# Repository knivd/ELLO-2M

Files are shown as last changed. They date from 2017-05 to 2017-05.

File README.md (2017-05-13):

# ELLO 2M
Electronics of the ELLO 2M DIY portable computer

http://ello.cc

https://www.crowdsupply.com/yellow-beak-computer/ello-2m

https://hackaday.io/project/9692-ello-2m

http://ello.referata.com/

ELLO 2M is a a PIC32-powered portable computer for hobby and education. It is built entirely from PCBs (no other casing!).

**ELLO 2M specifications**
* 32-bit PIC32 micro-controller with 128kB RAM (512kB RAM in the ELLO 2M² “hacker” version)
* 7-inch LCD touch-screen panel with 800x480 pixel resolution
* 3x micro-SD cards – one permanently built-in and two for removable storage
* Real-time clock
* 2.4GHz RF communication module with simple communication protocol
* Small speaker
* Optional on-board serial non-volatile data RAM
* Expansion receptacle
* Electronic prototyping space with up to 1156 holes
* 4500mAh battery for up to 12 hours of continuous operation (more in power-saving mode)
* Replaceable keyboard panels
* Composite construction from PCB panels only

**ELLO Features**
* ELLO is Thin - 6.4mm total without sockets, consisting of 6 stacked PCBs.
* Prototyping space - available on ELLO Geek and above, so you can create and test your projects using ELLO. 
* Real-time clock and buzzer
* Ample storage - 3 Micro-SD card slots and an internal serial FRAM for data and code storage.
* Built in RF module - which essentially emulates a wireless UART connection and also has an internal stack with ability for simple networking with similar devices. The range (by specs) is about 100 metres.
* keyboard - 2 layered keyboard to create pushable buttons, complete with optional backlighting and indicator LED.

**With ELLO you can**
* Learn how to program in BASIC and C; more programming languages will follow soon
* Have an open field to create programs for everything; ELLO is new and your programs will be needed
* Prototype electronic circuits and control them directly from your programs
* Develop own expansion boards
* Write your own games
* Play alone or connected with friends

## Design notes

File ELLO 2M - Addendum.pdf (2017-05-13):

# MMBasic for ELLO 2M and ELLO 2M² computers

# Addendum

to
Micromite MMBasic (original document) (http://geoffg.net/Downloads/Micromite/Micromite%20Manual.pdf)

# Micromite PLUS Addendum (original document) (http://geoffg.net/Downloads/Micromite/Micromite%20Plus%20Addendum.pdf)

MMBasic is a powerful implementation of the BASIC language with full floating point support, string variables, long variable names, multi-dimensional arrays, graphics, low-level driver support, and many more features.

The ELLO 2M and ELLO 2M²
computers use MMBasic for Micromite Plus, and also contain some additions and improvements, some of which in the form of extra commands and functions, but the majority of them invisible to the end user. These additions allow more effective utilisation of the hardware capabilities of ELLO 2M and ELLO 2M²

This manual describes only the additions and changes introduced for the support of the ELLO 2M and ELLO 2M²
computers. It does not replace the original MMBasic manual but only completes it with the additional information.

ELLO 2M and ELLO 2M²
computers are designed and manufactured by Yellow Beak Computer, Ltd. © 2015-2017
This manual is licensed under CC BY-NC-SA 3.0

© Mai 2017
Document Revision 4

ELLO 2M Keyboard

ELLO 2M and ELLO 2M²
are built as standalone computing systems with own keyboard and display. The keyboard layout is a mix of the standard US and UK keyboards with some new touch for more universality.

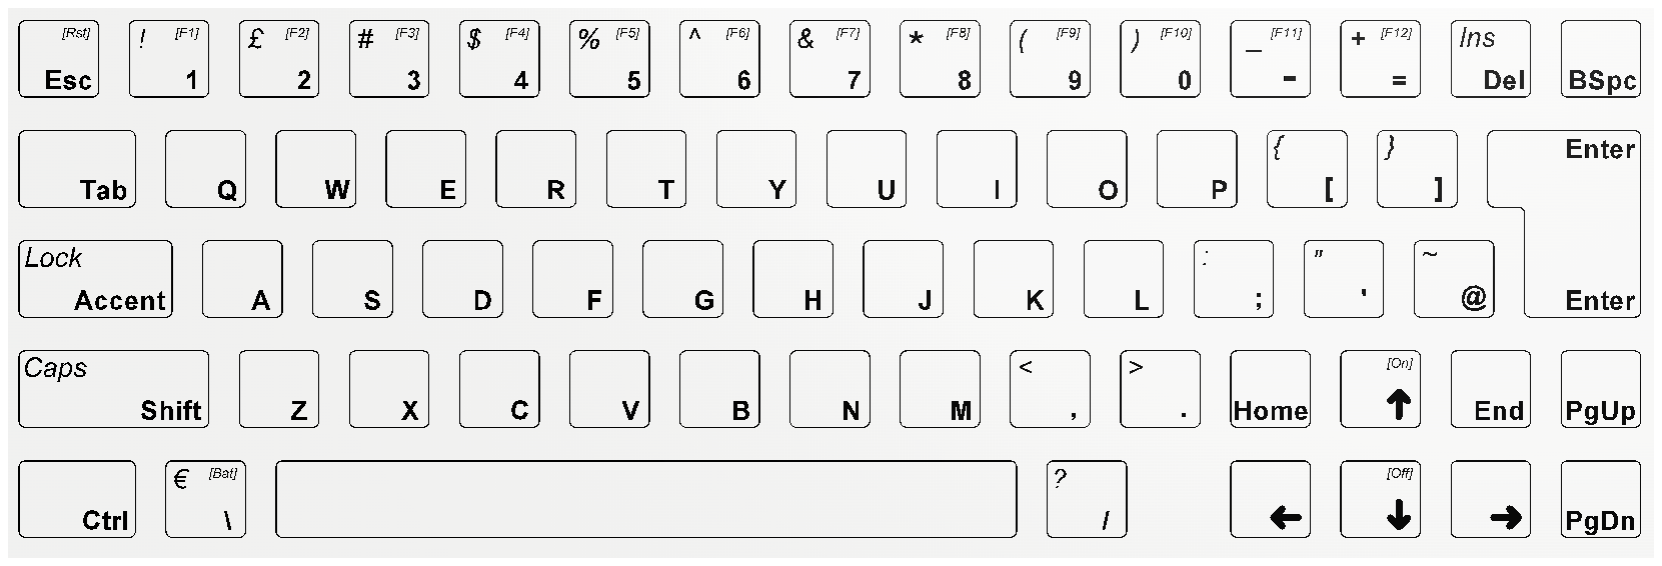
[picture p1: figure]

Some keys have small texts enclosed in square brackets, such as [F1], [Rst], etc.
These functions are accessible by pressing and holding the key “Ctrl” while pressing the key with the indicated function.

Four of the keys with text in square brackets require additional explaining:
- The key [On] is to switch the system on by holding “Ctrl” and [On] for about two seconds.
- The key [Off] switches the system off. It requires holding for about 4 seconds.
- The key [Rst] performs system reset after about 3 seconds.
- The key [Bat] is reserved for battery testing functionality in future.

An obvious difference is the “Accent” key which has replaced the traditional “Caps Lock”. It works exactly like the “Shift” key, and its function is to enable easy access to all characters from the extended part of the ASCII table. When pressed and held, and another key is pressed, it will produce a character from the extended codes of the table. The most used ones are the language accent characters such as “ë” or “ç”, hence the name of the key.

Keyboard layout in accent mode

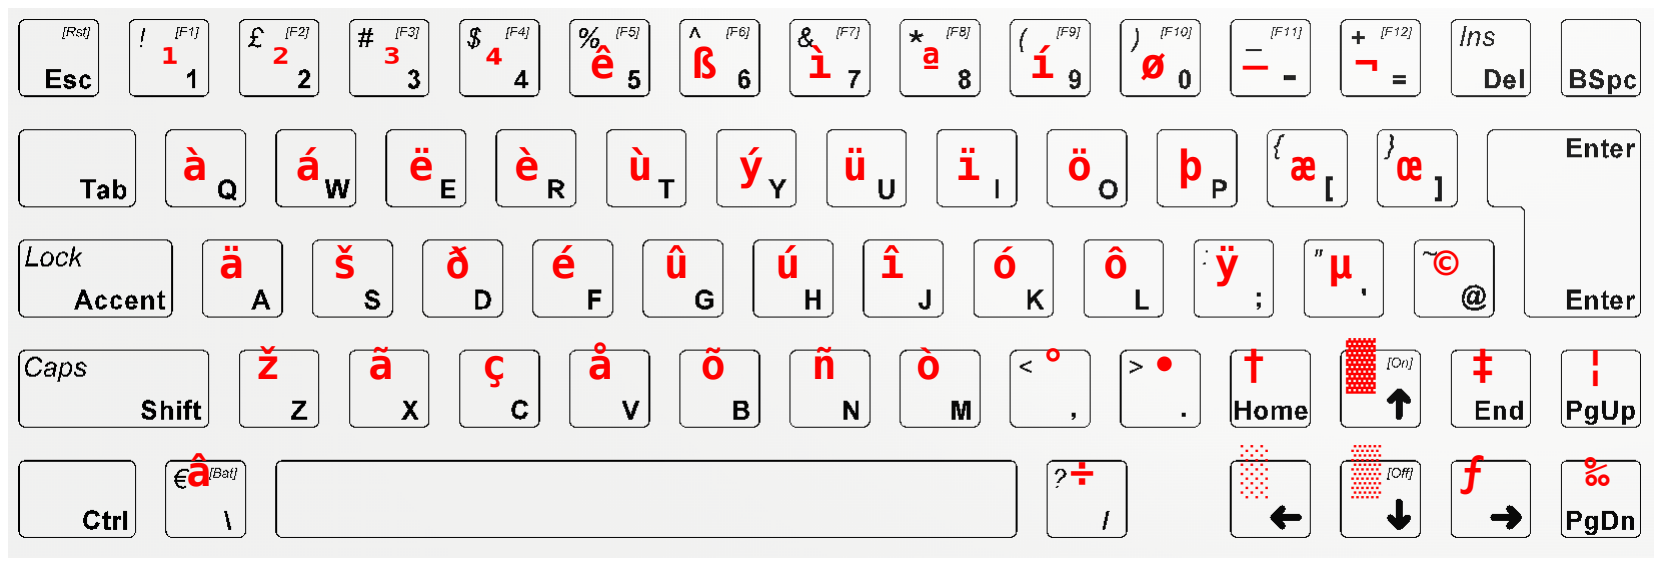
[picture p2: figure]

MMBasic Addendum for ELLO 2M and ELLO 2M²
computers | Page 2 / 10

Keyboard layout in Shift-Accent mode

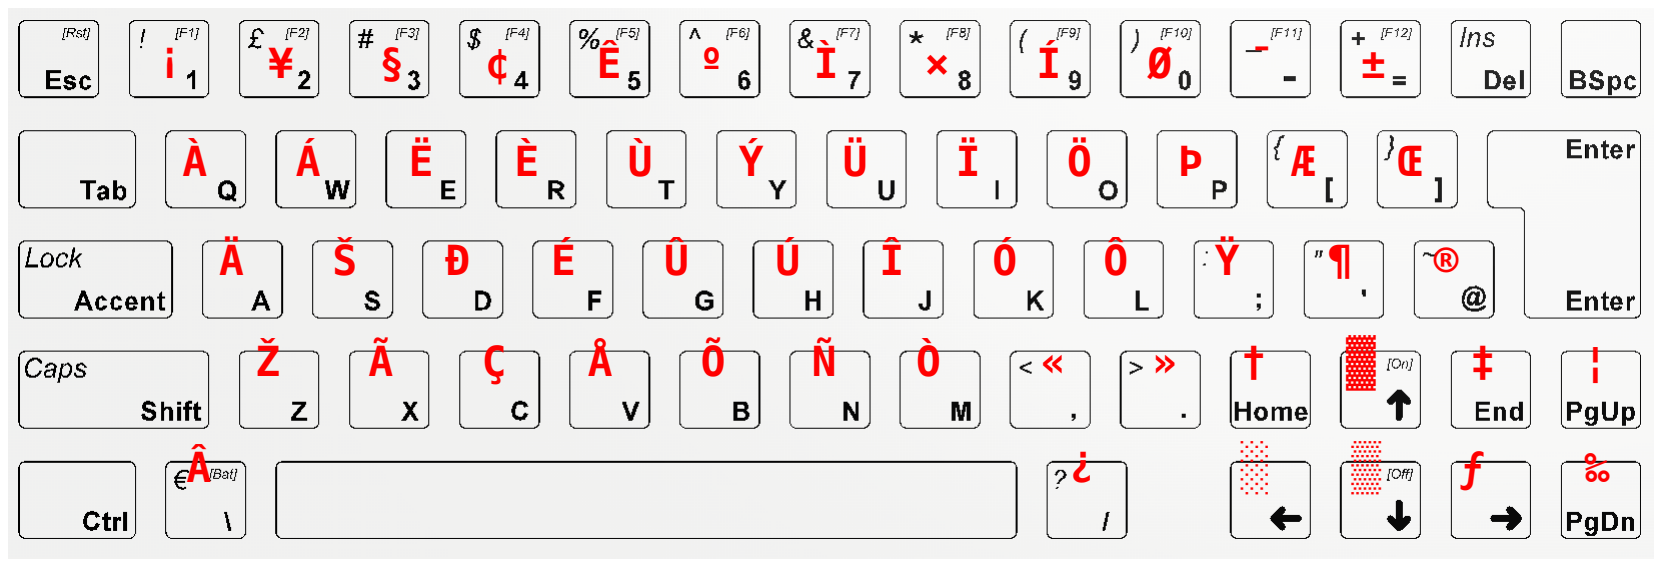
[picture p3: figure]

When the “Accent” key is double-pressed (quickly pressed twice), it enters in “Accent Lock” mode where the keyboard produces accented characters without the need to hold “Accent” continuously. Another double press cancels the mode.

The Shift character operates in the same manner – a double press of the “Shift” key is equivalent of “Caps Lock” activated.

Both “Accent” and “Shift” keys are independent and can be independently locked and unlocked – for example to continuously produce capital accented characters.

The current mode is displayed by changing the colour of the light indicator “ST”
- Normal operation mode (no lock to “Accent” or “Shift”): blue
- “Caps Lock” mode: white
- “Accent Lock” mode: yellow
- “Accent Caps Lock” mode: red

Another difference is the lack of “Insert” key. It is now moved to the “Del” key in shift mode.

Program and Data Storage

Up to five MMBasic “drives” are available for storing and loading programs and data:

- Drive “A:” (only available in ELLO 2M²
) a virtual drive using part of the internal flash memory and has size of about 800k. It can be used as general data and program storage as well as it is the default place where the help information is stored as a separate system file.
- Drives “B:”, “C:”, “D:”, and “E:” are supported in the system. With the exception of the last one, the first three hard SD card connectors installed on the PCB1 board. Supported are MMC, SD or SDHC memory cards formatted as FAT16 or FAT32 with capacities up to 64 Gigabytes.

File names must be in 8.3 format (8 characters for file name and 3 characters for extension), prefixed with an optional drive prefix A: or B: (the same as DOS or Windows).

Long file names and directories are not supported. The default drive after power on and reset events is B: and it can be changed with the command DRIVE.

During start up drive B: will be selected as default. A new drive can be selected by using the DRIVE command. For example DRIVE “C” will select drive C: as default. Once a drive has been selected, all file commands and functions will refer to files and data on that drive, until a new drive is selected by another DRIVE command.

Drive A: does not support hierarchic organisation with folders. All files in A: only exist in the root folder. However a file in A: can be made “hidden” if its name starts with the “.” character. For example the file MYPROG.BAS in A: is a normally visible file, while the file .MYPROG.BAS will not be seen in the FILES command. Making files in A: hidden can be used to protect important system files from being inadvertently deleted or corrupted in other way by the user.

When connected to a PC via USB, the A: drive appears as accessible data storage drive on the computer. This feature is always available and does not require any user interaction. In some cases that might be undesired and can be permanently disabled with command OPTION MSD OFF. If needed it can be enabled again with the command OPTION MSD ON.

Full 8-bit ASCII support

The ELLO 2M and ELLO 2M²
version of MMBasic supports the full 8-bit character table according to ISO-8859-15. Additional characters have been assigned to the unused codes as well. The full table is shown below.
A full 224-character 10x20 pixel font is also built-in as font #97. It is the default console font.

Character table in ELLO 2M and ELLO 2M²

hex | 00 | 01 | 02 | 03 | 04 | 05 | 06 | 07 | 08 | 09 | 0A | 0B | 0C | 0D | 0E | 0F
00 | NON-PRINTABLE CODES
10
20 | | ! | “ | # | $ | % | & | ‘ | ( | ) | * | + | , | - | . | /
30 | 0 | 1 | 2 | 3 | 4 | 5 | 6 | 7 | 8 | 9 | : | ; | < | = | > | ?
40 | @ | A | B | C | D | E | F | G | H | I | J | K | L | M | N | O
50 | P | Q | R | S | T | U | V | W | X | Y | Z | [ | \ | ] | ^ | _
60 | ` | a | b | c | d | e | f | g | h | i | j | k | l | m | n | o
70 | p | q | r | s | t | u | v | w | x | y | z | { | | | } | ~
80 | ░ | ▒ | ▓ | ƒ | √ | … | † | ‡ | ¦ | ‰ | ≤ | ← | ↑ | ≈ | π | Ω
90 | ∞ | ─ | ⁴ | ∫ | ¤ | │ | ½ | ¼ | ¾ | ™ | ≥ | → | ↓ | ∆ | ∏ | ∑
A0 | | ¡ | ¢ | £ | € | ¥ | Š | § | š | © | ª | « | ¬ | ― | ® | ¯
B0 | ° | ± | ² | ³ | Ž | µ | ¶ | • | ž | ¹ | º | » | Œ | œ | Ÿ | ¿
C0 | À | Á | Â | Ã | Ä | Å | Æ | Ç | È | É | Ê | Ë | Ì | Í | Î | Ï
D0 | Ð | Ñ | Ò | Ó | Ô | Õ | Ö | × | Ø | Ù | Ú | Û | Ü | Ý | Þ | ß

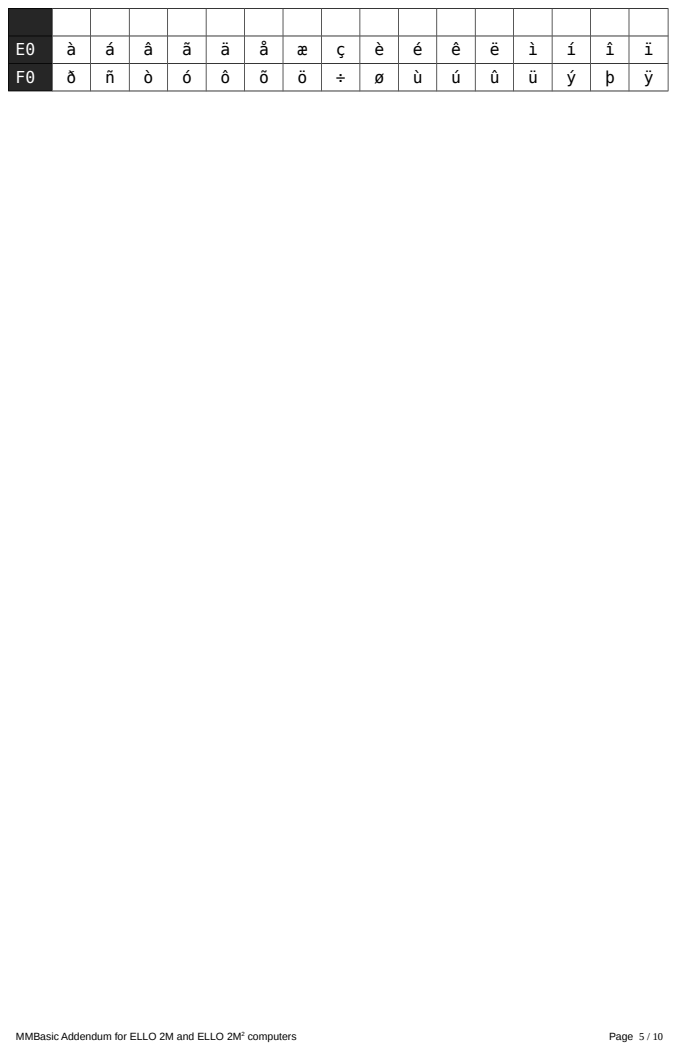
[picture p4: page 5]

IMPORTANT: A string that starts with an extended character (i.e. with ASCII code greater than 127), must be preceded by two double quotes.

Example: ""µmite"

This rule is required only if the first character of the string is an extended code.

Expansion Connector

ELLO 2M and ELLO 2M²
computers have expansion connector with pinout as shown in the pictures below. The connector is a standard 36-pin female square pin receptacle with 2.54mm (0.1”) pitch. It can be used to connect various expansion boards or prototype jumper wires.

ELLO 2M expansion connector

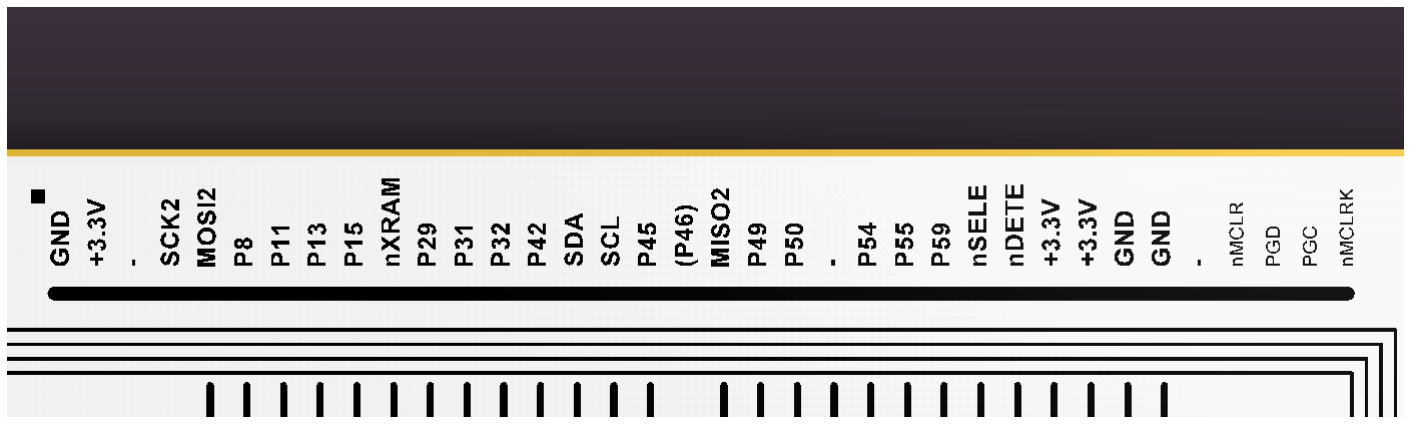
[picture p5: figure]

ELLO 2M²
expansion connector

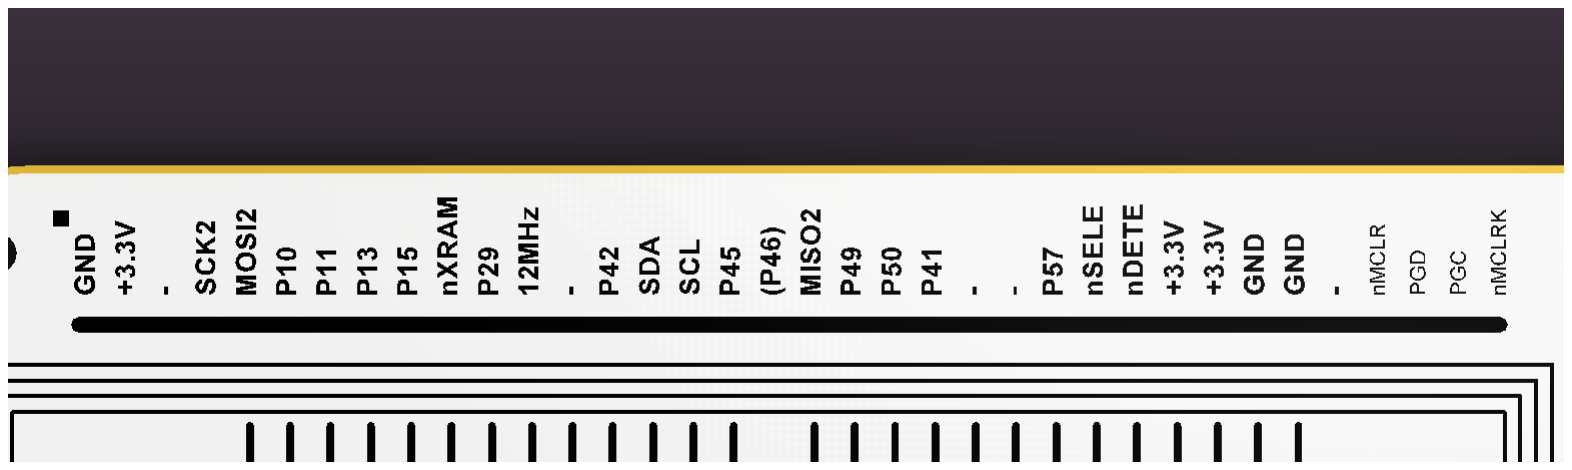
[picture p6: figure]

Prototyping space

ELLO 2M and ELLO 2M²
computers have prototyping space that can be used for building custom schematics. It offers 1156 holes. There are 4 surrounding “orbital” lanes and 3 dedicated areas. The wiring is as shown on the next page.

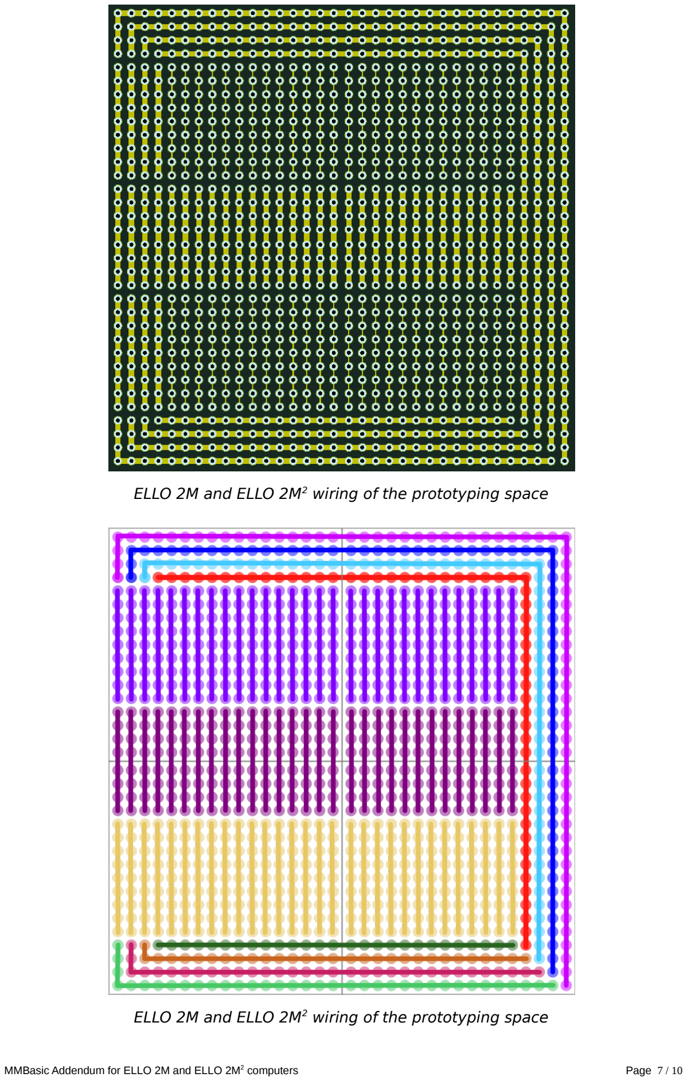
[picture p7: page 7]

ELLO 2M and ELLO 2M²
wiring of the prototyping space

ELLO 2M and ELLO 2M²
wiring of the prototyping space

Firmware Updates

MMBasic on ELLO 2M and ELLO 2M²
can update itself with a newer version of the firmware to include new features or fix previously known problems.

The command to activate this functionality is FWUPDATE. It must be executed in direct mode with the system attached to a PCB via USB cable.

Select the button “Open HEX File”. A file selection dialog will appear. Choose the file with the new firmware.

Press “Program/Verify” and wait until the process is complete.

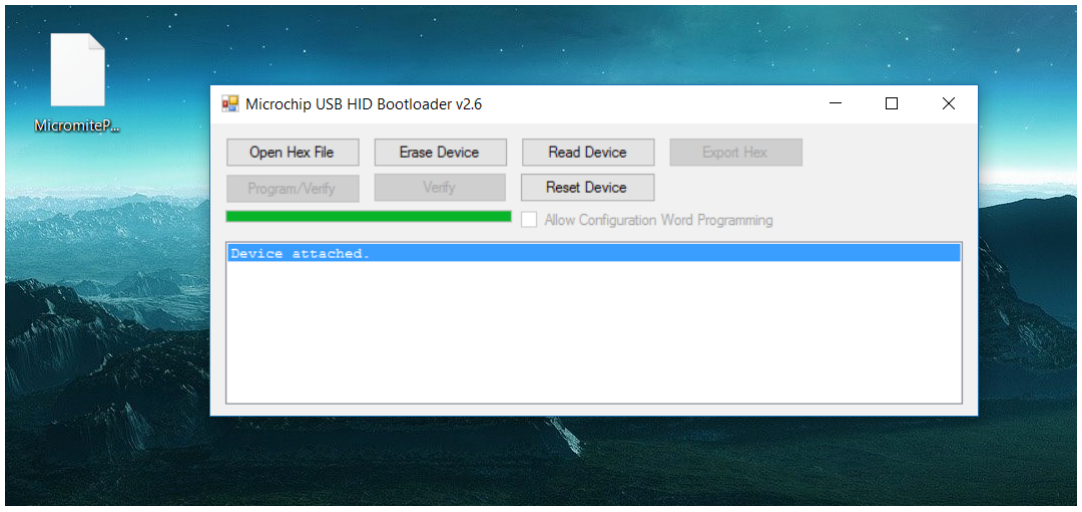
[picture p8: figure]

If due to some unfortunate event the update gets interrupted before completion (USB cable pulled out, for example), MMBasic will not be available anymore. There is a more “hardware-type” way to restore the firmware even from that situation.
Switch the system off, connect a jumper wire between the pins marked as “PGD” and “GND” on the expansion connector, and switch the system again. It will be forced back in bootloader mode.

Now remove the jumper cable (IMPORTANT!) and start the process for updating the software.

And finally, of course there is always the third option to upload new firmware by using ICD3 or Pickit3 or similar programmer. Connect the programmer using prototype jumper wires to the pins marked “MCLR” (not “MCLRK”!), “PGC”, “PGD”, “+3.3V”, and “GND”. Switch the system on and upload the new firmware using the relevant PC software such as MPLAB IPE or other.

Full list of the added or changed commands in ELLO 2M and ELLO 2M²

Note: Square brackets indicate that the parameter or characters are optional.

Sinc
e

Name and
parameters

Description

V5.2 FWUPDATE | Executes the bootloader for firmware update. The system
must be connected to a PC via USB and the firmware update software must be running.
V5.2 DRIVE drivespec$ Change the default drive used for file operations that do not specify a drive to that specified in 'drivespec$'. This can be the string “A”, “B”, “C”, “D”, or “E”
ELLO 2M allows execution of an implied DRIVE command. Hence for example DRIVE “A” can be written just as A:
See also the predefined read-only variable MM.DRIVE.
V5.3 INIT drivespec$ | Initialise (format) specified drive letter. All data on the
drive will be destroyed
V5.3 FILES [fspec$] [A]
or
DIR [fspecs$] [A]

Lists files in the current directory on the SD or internal drive (drive A:).
The SD card may use an optional ‘fspec $’. Question marks (?) will match any character and an asterisk (*) will match any number of characters. If omitted, all files will be listed. For example:
*.* | Find all entries
*.TXT | Find all entries with an extension of TXT
E*.* | Find all entries starting with E
X?X.* | Find all three letter file names starting and
ending with X
An optional parameter ‘-A’ displays the file attributes when executed on drive B: and ALL files (including the hidden ones) on drive A:
V5.3 IMAGEA CREATE
“file”
or
IMAGEA LOAD “file”

Only available in ELLO 2M²
Creates or loads full binary image of drive A:
The images are searched and created in the current active drive. When loading a new image the entire previous content of A: is destroyed

V5.3 HELP [keyword$] | Only available in ELLO 2M² Displays help information about the provided keyword. From the command line keyword$ without enclosing quotes will work for almost all system words, however it is recommended that keyword$ is always enclosed by quotes or at least the opening one is present. Examples: HELP HELP CIRCLE HELP ‘CIRCLE or HELP ‘CIRCLE’ HELP “CIRCLE or HELP “CIRCLE” The command is also able to find in many cases the most suitable match for a partial or mistyped keyword. As in the examples above HELP CICLE will lead to displaying help information about the CIRCLE command as a closest match to the parameter ‘CICLE’.
V5.3 OPTION MSD ON | OFF | Only available in ELLO 2M² Enable (parameter ON) or disable (parameter OFF) file access to the internal drive A: by a host PC via USB connection By default this function is activated. Note that the access to B: may not work on MacOS powered machines. OPTION MSD OFF is recommended in those cases.

Full list of the added or changed functions and read-only variables in ELLO 2M and ELLO 2M²

Note: Square brackets indicate that the parameter or characters are optional.

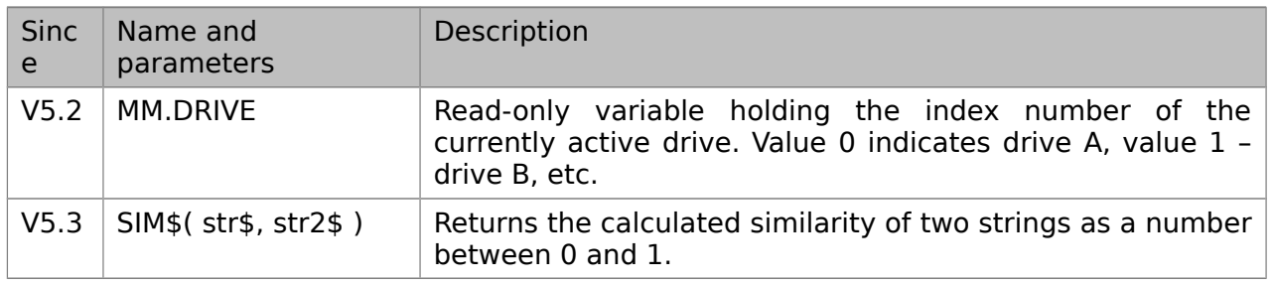
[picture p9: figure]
Sinc e; Name and parameters; Description; drive B, etc.; between 0 and 1.

V5.2 MM.DRIVE | Read-only variable holding the index number of the currently active drive. Value 0 indicates drive A, value 1 –
V5.3 SIM$( str$, str2$ ) | Returns the calculated similarity of two strings as a number

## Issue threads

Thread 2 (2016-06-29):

all pdfs are just 100kb files that are completely white

buzztiaan, 2016-06-29:
eh, oops?

knivd, 2016-06-29:
I just checked all PDFs, and they are fine. Using Adobe Reader and it opens both the schematics and the 3D renders as well.

buzztiaan, 2016-07-01:
adobe reader isnt free software

knivd, 2016-07-05:
I believe it is. The schematic files can be open with any PDF reader. I am not sure about the 3D renders though, but they are not critical

buzztiaan, 2016-07-11:
free software is not defined like you think it is

blu, 2016-07-11:
Konstantin, some of the PDFs have issues opening in evince (a very popular X11-based reader) as well as in the default PDF reader in iOS. The problematic PDFs are:

panel_MX470.pdf
PCB0.pdf
PCB1_MX470.pdf
PCB2.pdf
PCB3a.pdf
PCB3.pdf
PCB4.pdf

And here's what evince reports to stderr when trying to open one of those:

** (evince:3753): WARNING **: Unimplemented annotation: POPPLER_ANNOT_3D.  It is a known issue and it might be implemented in the future.

I understand AdobeReader handles those annotations just fine, but could you, please, consider producing a version of the PDFs without those annotations or using a different type of annotation?

Closed 2016-07-05.

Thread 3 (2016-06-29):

Design not made with available FOSS tools

buzztiaan, 2016-06-29:
Could you please redo the pcb in kicad? ty

knivd, 2016-06-29:
I have never used kicad before, so I can't promise that. But will have a look at it to see if the current design can be imported there somehow

buzztiaan, 2016-07-01:
i would totally love you if you fixed this issue :)

using non-opensource tools to make opensource designs is just not-done, and i cant clone your project until it does use opensource tools

knivd, 2016-07-05:
KiCAD proves to be too distant for my old habits, but converting the design to CircuitMaker (which is free) is quite easy. I just tried and it works perfectly fine. It opens the schematic files directly, but doesn't open the PCB files. However I will export them into CM format and will upload the files in the coming days, and the entire ELLO 2M computer will be available through the CircuitMaker community as well.

buzztiaan, 2016-07-05:
free but not foss ;)

On Tue, Jul 5, 2016 at 10:34 PM, Konstantin Dimitrov <
notifications@github.com> wrote:

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

buzztiaan, 2016-07-11:
please learn KiCAD or stop calling your project OSHW

knivd, 2016-07-11:
I consider this post quite aggressive. Don't want to learn KiCAD.
My design is open-source because you can see the source of it, but it is entirely up to you what you can make out of it.

buzztiaan, 2016-07-11:
i understand your adversion towards actual improvement of your knowledge, but to adhere to being actual OSHW you have no choice.

Closed 2016-07-11.

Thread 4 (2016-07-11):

Please make your OSHW project actual OSHW

buzztiaan, 2016-07-11:
http://freedomdefined.org/OSHW

This is depending on the availability of actual FOSS software to edit your sourcefiles.
The current design you are trying to push lacks this.

Please improve.

buzztiaan, 2016-07-11:
If you fail to adhere to the specification listed above, I would recommend you just drop the OSHW definition from your project.

cpavlina, 2016-07-11:
Please, point to the specific section of the definition that requires it. I'm not seeing it.

buzztiaan, 2016-07-11:
what use is source when you need to pay to edit it?

cpavlina, 2016-07-11:
Doesn't matter, the definition allows it, so there's no "issue" here. If you want to have a philosophical debate with me or the project owner about whether it's really in the "spirit" of things, that can be done in a side channel, but this is an inappropriate and frankly asinine thing to make an "issue".

knivd, 2016-07-13:
I am only providing free and open hardware design. I don't offer the EDA tools for it. Yet, it can be used with CircuitMaker, which itself is a FREE CAD. Unfortunately this is the best I can do. If you don't consider it free and open enough for you, please don't use it.
Thanks

Closed 2016-07-13.

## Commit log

2016-05-27 Added mechanical framing boards and keyboard panel
    [PCB0.PcbDoc, PCB2.PcbDoc, PCB3.PcbDoc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]
2016-05-27 Added PCB1 and schematic files
    [ELLO 2M.PrjPcb, expansions.SchDoc, keyboard.SchDoc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]
2016-05-28 Small updates in PCB0 and PCB3a
    [PCB0.PcbDoc, PCB3a.PcbDoc]
2016-05-31 Updated comment in the BOM
    [BOM_MX470.xls]
2016-06-01 Much more clear assembly drawing file
2016-06-04 PCB2 r3a with improved prototyping layout
    [PCB2.PcbDoc]
2016-06-12 Slight revision in the outline of PCB2, plus BoM
    [BOM_PCB2.xls, PCB2.PcbDoc]
2016-06-17 BOM updated with better quality LCD panel
    [BOM_MX470.xls]
2016-06-29 Fixed mistake in the component description field
    [BOM_MX470.xls]
2016-07-06 PCB files in Circuit Maker format
2016-07-16 Added keyboard panel for 2M²
    [panel_MZEF.PcbDoc]
2016-07-16 3D renders of PCB1 for 2M and 2M²
2016-07-16 BOM for 2M²
    [BOM_MZEF.xls]
2016-07-16 ELLO 2M² schematics
2016-07-16 ELLO keyring
    [keyring.PcbDoc]
2016-07-19 Fixed small issue with the PCB outline
2016-07-28 Front panel fixed according to the new firmware development where A: is reserved for future internal drive
    [panel_MX470.PcbDoc, panel_MZEF.PcbDoc]
2016-09-12 removed R60 and R61 from installation in BOM
2016-09-13 Files optimised for manufacturing of configurations with prototyping sockets
2016-09-13 Updated BOM
2016-09-15 Updates in BOM and schematic (I2C pull-up values)
2016-09-16 Updates in BOM and schematic
2016-09-16 Updated BOM with sockets which will make PCB3a redundant
2016-09-27 Revised files for the smaller PGA sockets from Antenk
2016-10-19 Fixed distance between the new PGA sockets
2016-11-02 slightly wider socket cutout for easier assembly
2016-11-12 Corrected soldermask expansion on the keyboard comb pads
2016-11-28 Modified schematic to move SD card detect from pin 38 to pin 32
2016-12-25 Replaced the arrow characters with drawn lines
    This is to avoid potential problems when the Wingdings font is not installed
2016-12-25 Latest revision updated with the file "Assembly Information"
2016-12-27 Version 1612.1
    - Fixed bugs for some accented characters
    - Corrected timings for special buttons
2017-01-05 Current build of MMBasic for ELLO 2M
2017-05-13 Revision 4
    Prototyping space wiring picture added
2017-05-16 Current help file for ELLO 2M² (not actual!!!)
